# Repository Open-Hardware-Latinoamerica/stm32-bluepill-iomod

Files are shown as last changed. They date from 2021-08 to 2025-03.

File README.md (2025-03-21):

# STM32-BluePill Digital I/O Board

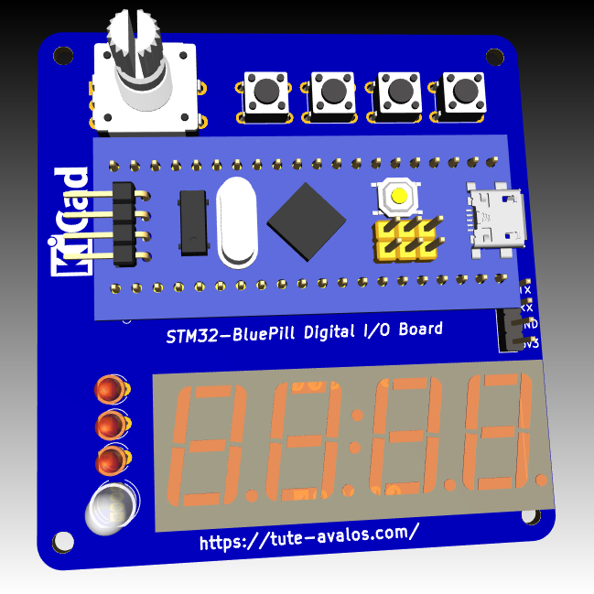
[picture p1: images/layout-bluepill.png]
STM32-BluePill Digital I/O Boadr


This Open Source Hardware PCB proyect is a tool for teach µController (microcontroller) programming. Feel free to use, modifie or improobe it in any way you want. The schematics and the layout was designed on [KiCad EDA Software](https://kicad.org/).

More information (Spanish only): [BluePill STM32 Digital I/O Board v3.0](https://blog.tute-avalos.com/2021/08/18/blue-pill-stm32-digital-i-o-board-v3-0/)

- - -

Este PCB es un poryecto de Hardware Libre y Abierto, pensado para enseñar programación de µControladores (microcontroladores). Sientase libre de usarlo, modificarlo y/o mejorarlo en cualquier sentido que desee. Los esquemáticos y el PCB fueron diseñados utilizando el software [KiCad EDA](https://kicad.org/).

- - -

# Pinout Configuration

## OUTPUTS

| PIN  | Conection | Active | | PIN  | Conection | Active |
|---|---|---|-|---|---|---|
| PB9  | LED1 - Red | LOW | | PA0  |  Seg E |  HIGH  |
| PB8  | LED1 - Green  | LOW | | PA1  |  Seg D |  HIGH  |
| PB7  | LED1 - Blue | LOW | | PA2  |  Seg P |  HIGH  | 
| PB6  | LED2 | LOW | | PA3  |  Seg C |  HIGH  |
| PB5  | LED3 | LOW | | PA4  |  Seg G |  HIGH  |
| PB4  | LED4 | LOW | | PA5  |  Seg B |  HIGH  |
| PC13 | Build-in LED  | LOW | | PA6  |  Seg F |  HIGH  |
|  - | - | - | | PA7  |  Seg A |  HIGH  |
|  - | - | - | | PB0  |  Disp 1 (MSD) |  LOW |
|  - | - | - | | PB1  |  Disp 2 |  LOW |
|  - | - | - | | PB10 |  Disp 3 |  LOW |
|  - | - | - | | PB11 |  Disp 4 (LSD) |  LOW |

## INPUTS

| PIN  | Conection | Active |
|---|---|---|
| PA15 | Rotary - A | LOW |
| PB3  | Rotary - B | LOW |
| PA8  | Rotary Switch | LOW |
| PB15 | Button 1 | LOW |
| PB14 | Button 2 | LOW |
| PB13 | Button 3 | LOW |
| PB12 | Button 4 | LOW |

## Reference

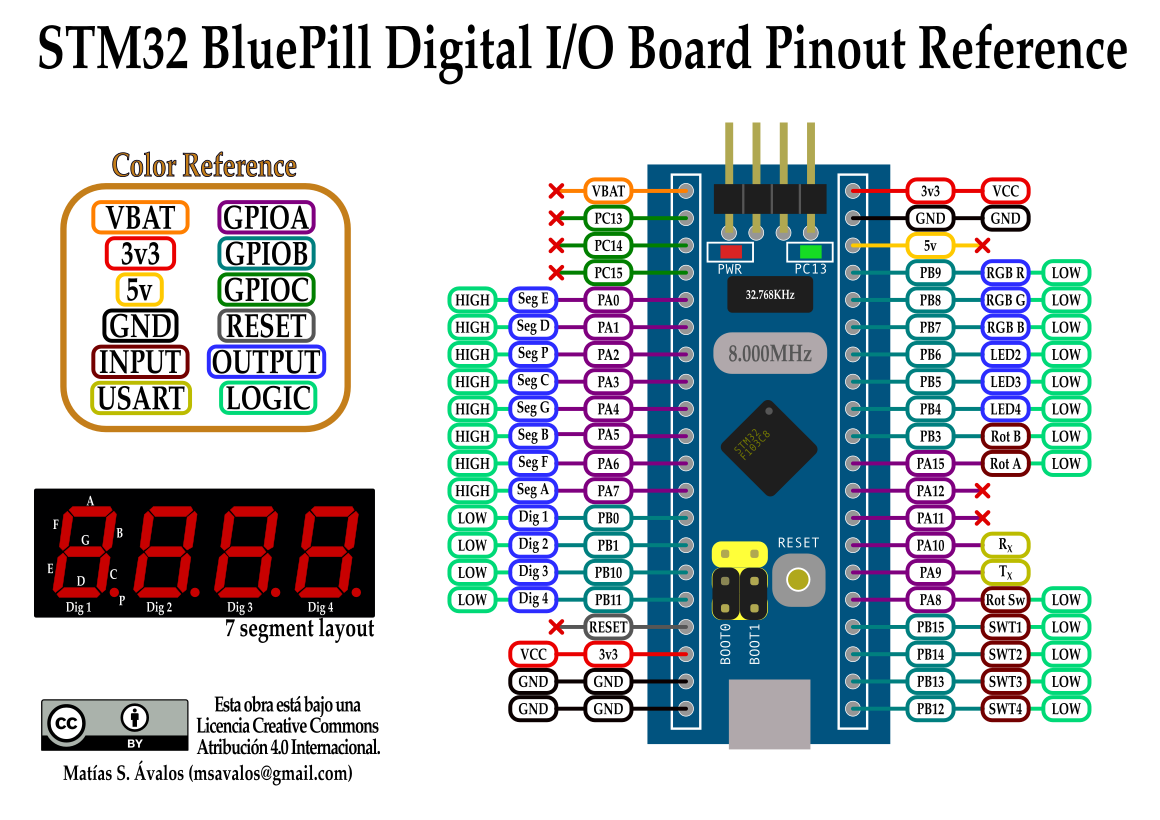
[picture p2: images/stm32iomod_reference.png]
Pinout reference


## Images

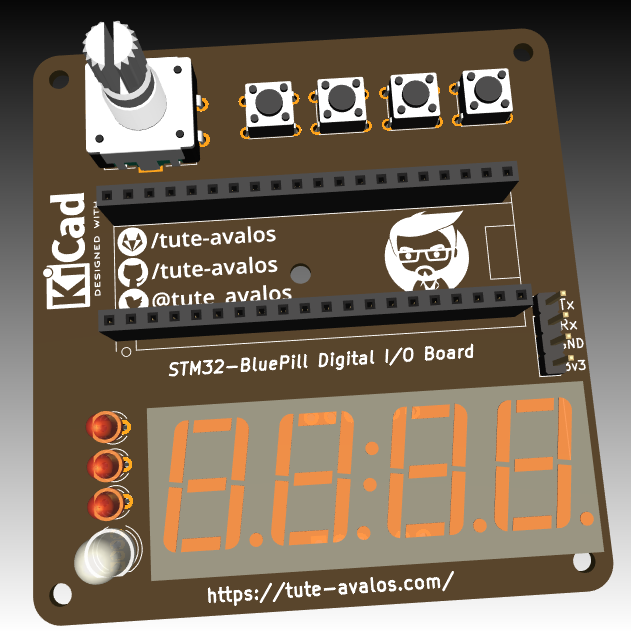
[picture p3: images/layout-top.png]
top layout
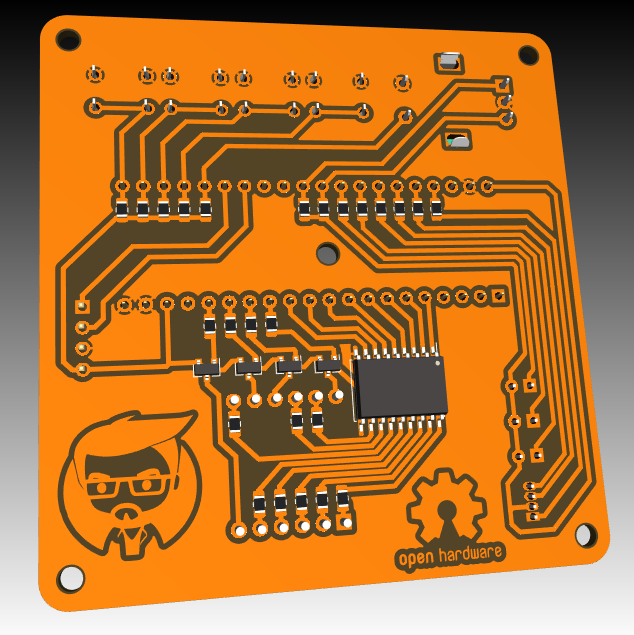
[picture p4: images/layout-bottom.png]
bottom layout
|  | |
|-|-|
|<p style="text-align:center;">top layout</p>|<p style="text-align:center;">bottom layout</p>|

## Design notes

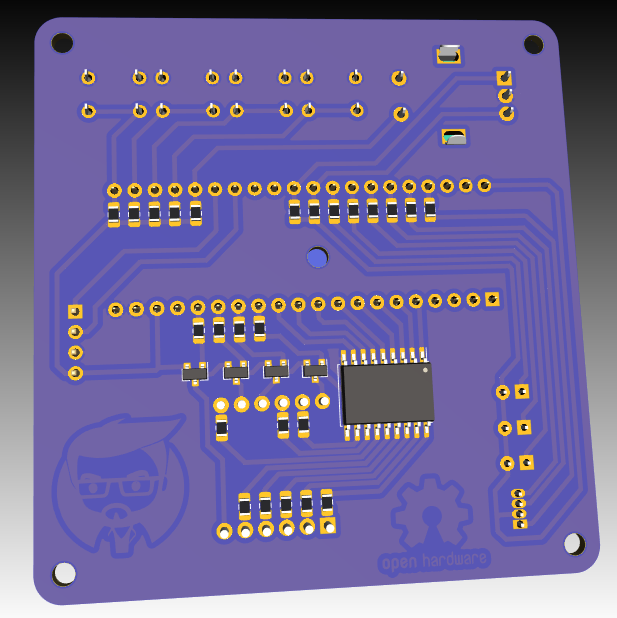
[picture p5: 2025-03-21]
images/layout-top-mask.png

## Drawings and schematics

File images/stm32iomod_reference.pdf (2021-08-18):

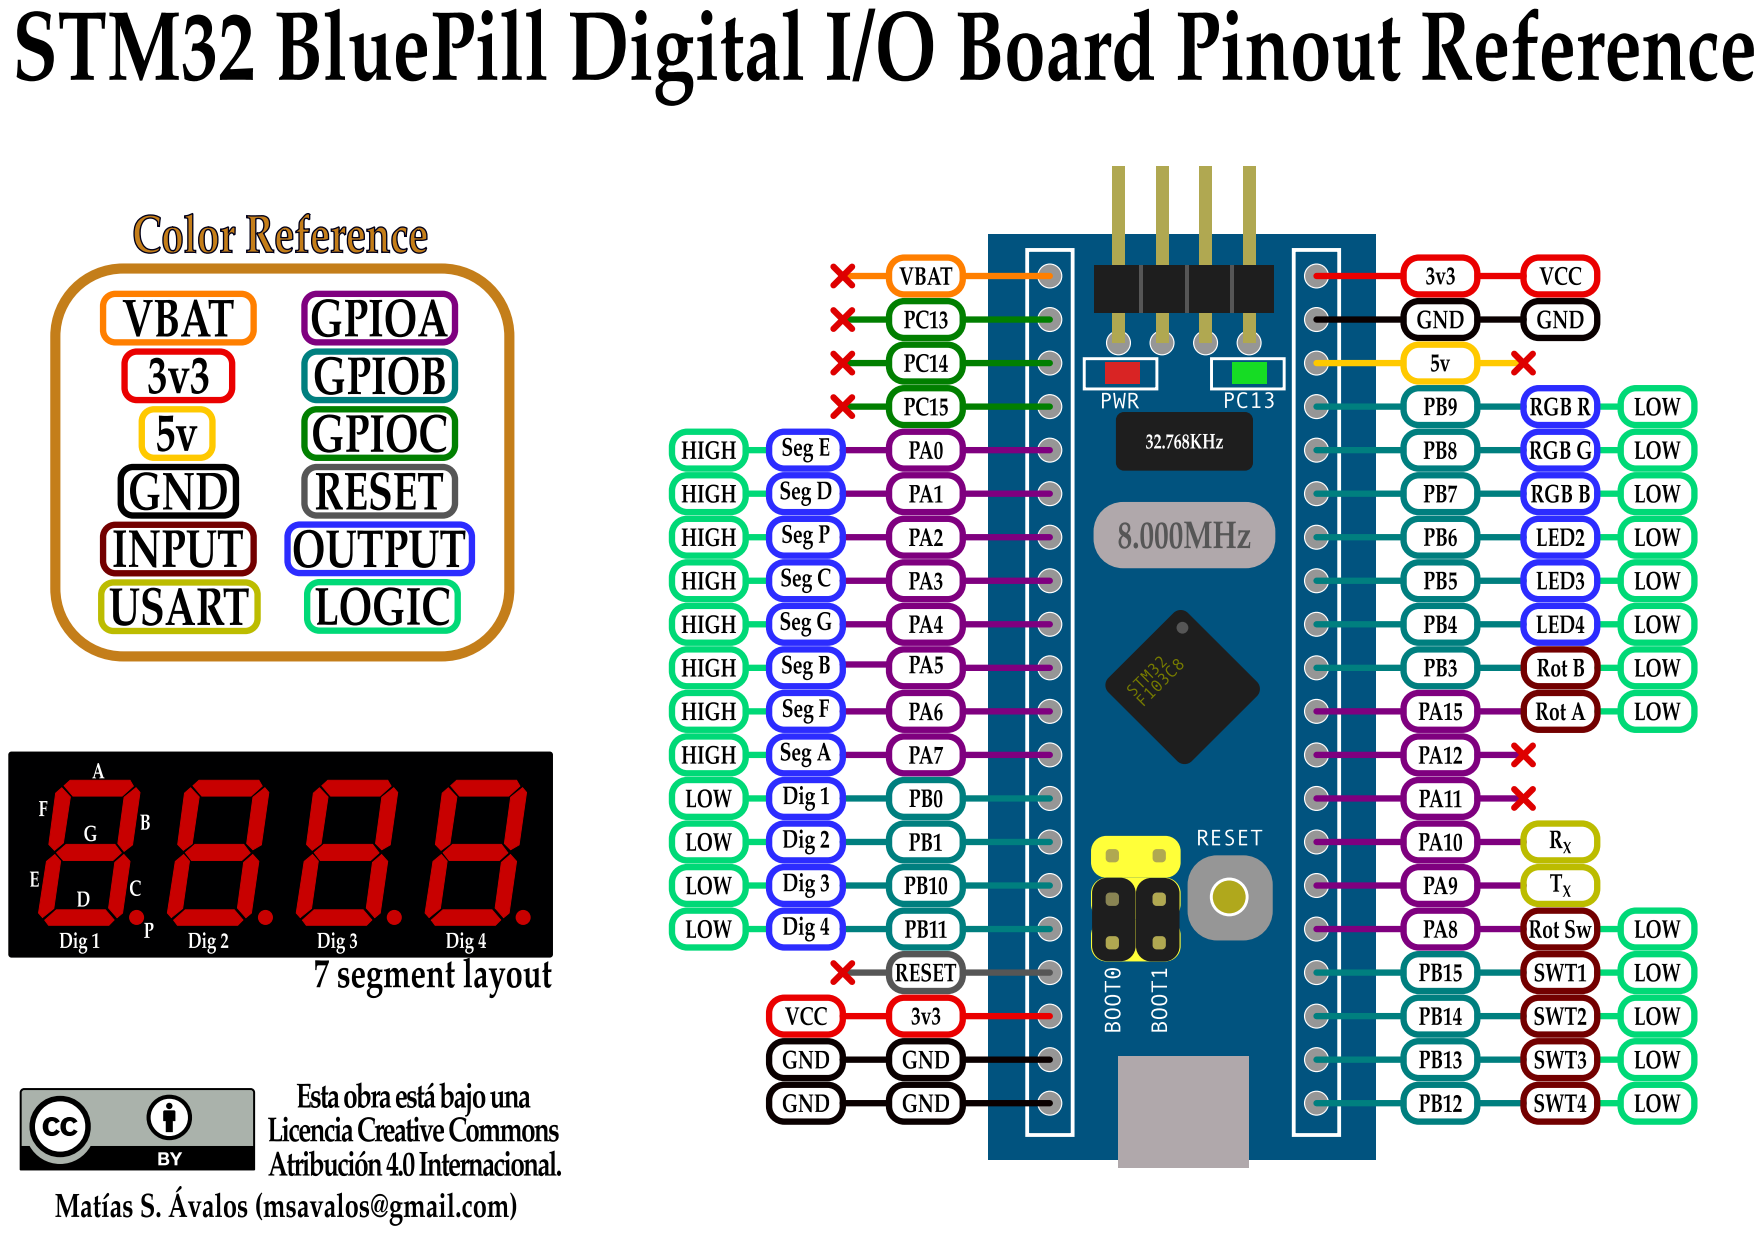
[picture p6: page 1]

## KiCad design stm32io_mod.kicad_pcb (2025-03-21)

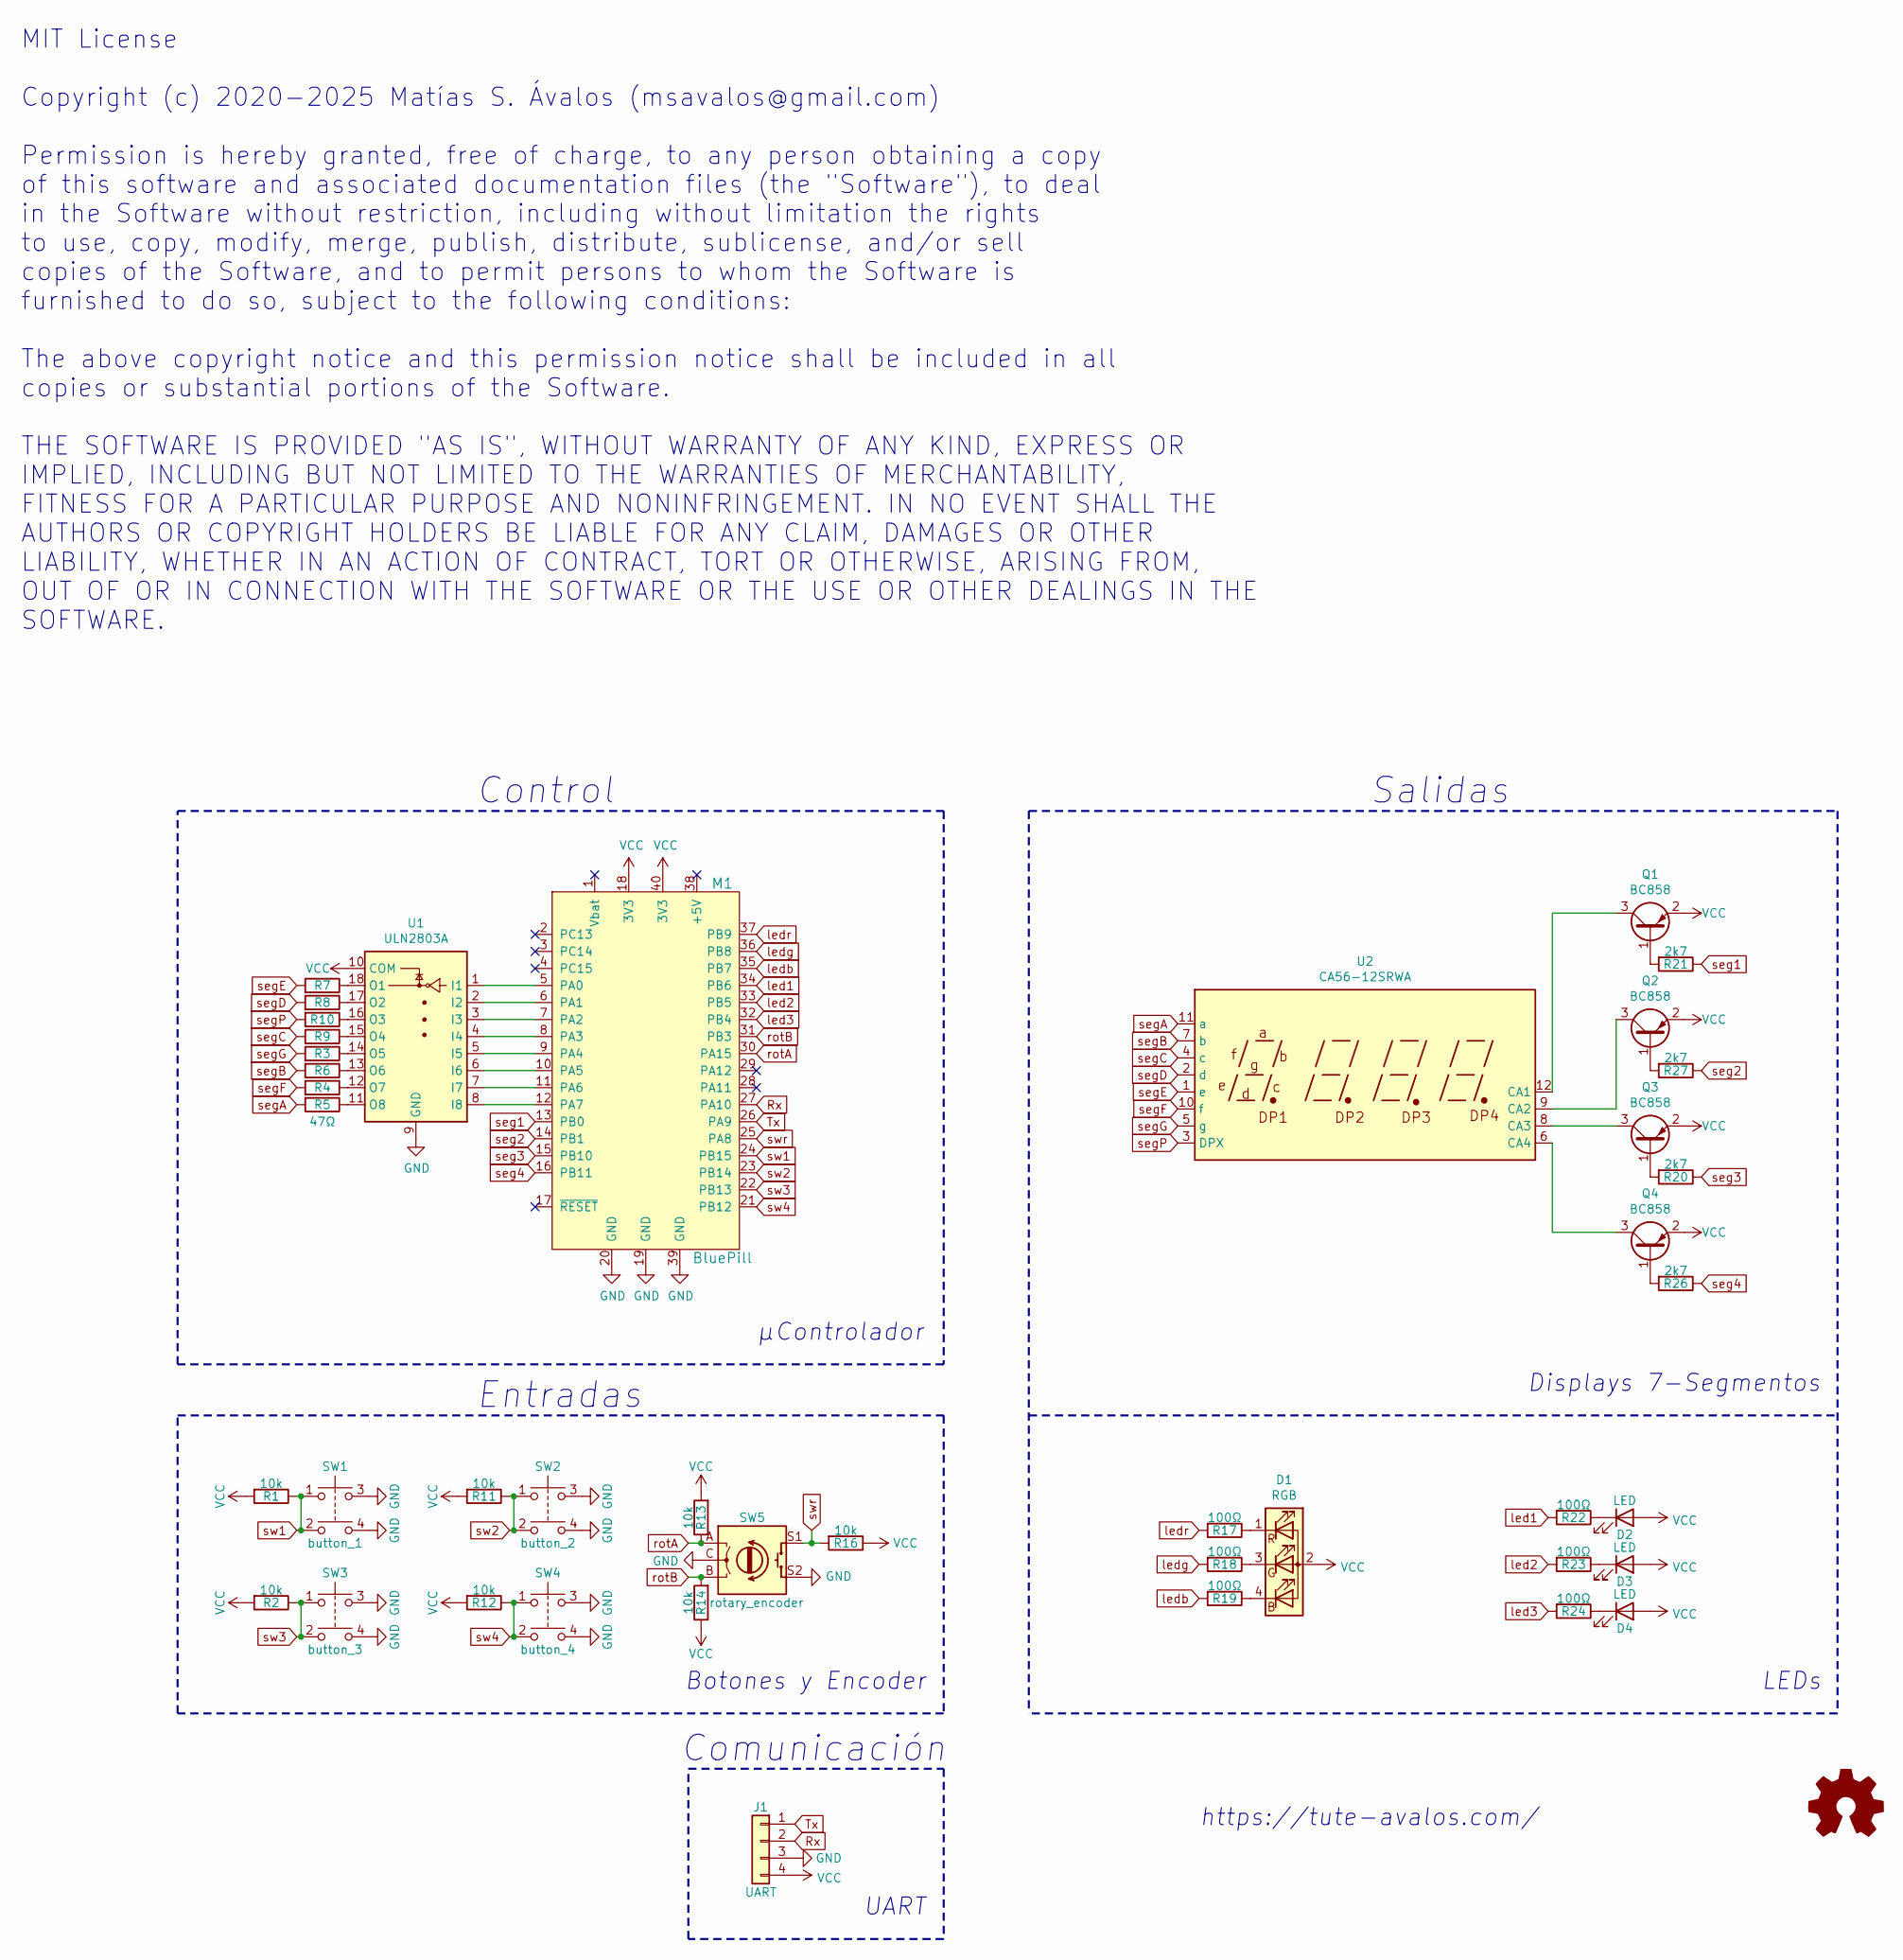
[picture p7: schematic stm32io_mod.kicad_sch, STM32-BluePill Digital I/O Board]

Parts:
D1: RGB; LED_D5.0mm-4_RGB
D2, D3, D4: LED; LED_D3.0mm_Clear
J1: UART; PinHeader_1x04_P2.54mm_Vertical
M1: BluePill
Q1, Q2, Q3, Q4: BC858; SOT-23
R1, R2, R11, R12, R13, R14, R16: 10k; R_0805_2012Metric_Pad1.15x1.40mm_HandSolder
R3, R4, R5, R6, R7, R8, R9, R10: 47Ω; R_0805_2012Metric_Pad1.15x1.40mm_HandSolder
R17, R18, R19, R22, R23, R24: 100Ω; R_0805_2012Metric_Pad1.15x1.40mm_HandSolder
R20, R21, R26, R27: 2k7; R_0805_2012Metric_Pad1.15x1.40mm_HandSolder
SW1: button_1; SW_TH_Tactile_Omron_B3F-10xx
SW2: button_2; SW_TH_Tactile_Omron_B3F-10xx
SW3: button_3; SW_TH_Tactile_Omron_B3F-10xx
SW4: button_4; SW_TH_Tactile_Omron_B3F-10xx
SW5: rotary_encoder; RotaryEncoder_Alps_EC11E-Switch_Vertical_H20mm
U1: ULN2803A; SOIC-18W_7.5x11.6mm_P1.27mm
U2: CA56-12SRWA

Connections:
GND: J1.3, M1.19 (GND), M1.20 (GND), M1.39 (GND), SW1.3, SW1.4, SW2.3, SW2.4, SW3.3, SW3.4, SW4.3, SW4.4, SW5.C, SW5.S2, U1.9 (GND)
unnamed: D1.1 (RK), R17.1
unnamed: D1.3 (GK), R18.1
unnamed: D1.4 (BK), R19.1
unnamed: D2.1 (K), R22.1
unnamed: D3.1 (K), R23.1
unnamed: D4.1 (K), R24.1
unnamed: M1.5 (PA0), U1.1 (I1)
unnamed: M1.6 (PA1), U1.2 (I2)
unnamed: M1.7 (PA2), U1.3 (I3)
unnamed: M1.8 (PA3), U1.4 (I4)
unnamed: M1.9 (PA4), U1.5 (I5)
unnamed: M1.10 (PA5), U1.6 (I6)
unnamed: M1.11 (PA6), U1.7 (I7)
unnamed: M1.12 (PA7), U1.8 (I8)
unnamed: Q1.1 (B), R21.2
unnamed: Q1.3 (C), U2.12 (CA1)
unnamed: Q2.1 (B), R27.2
unnamed: Q2.3 (C), U2.9 (CA2)
unnamed: Q3.1 (B), R20.2
unnamed: Q3.3 (C), U2.8 (CA3)
unnamed: Q4.1 (B), R26.2
unnamed: Q4.3 (C), U2.6 (CA4)
unnamed: R3.1, U1.14 (O5)
unnamed: R4.1, U1.12 (O7)
unnamed: R5.1, U1.11 (O8)
unnamed: R6.1, U1.13 (O6)
unnamed: R7.1, U1.18 (O1)
unnamed: R8.1, U1.17 (O2)
unnamed: R9.1, U1.15 (O4)
unnamed: R10.1, U1.16 (O3)
Rx: J1.2, M1.27 (PA10)
Tx: J1.1, M1.26 (PA9)
VCC: D1.2 (A), D2.2 (A), D3.2 (A), D4.2 (A), J1.4, M1.18 (3V3), M1.40 (3V3), Q1.2 (E), Q2.2 (E), Q3.2 (E), Q4.2 (E), R1.2, R2.2, R11.2, R12.2, R13.2, R14.1, R16.1, U1.10 (COM)
led1: M1.34 (PB6), R22.2
led2: M1.33 (PB5), R23.2
led3: M1.32 (PB4), R24.2
ledb: M1.35 (PB7), R19.2
ledg: M1.36 (PB8), R18.2
ledr: M1.37 (PB9), R17.2
rotA: M1.30 (PA15), R13.1, SW5.A
rotB: M1.31 (PB3), R14.2, SW5.B
seg1: M1.13 (PB0), R21.1
seg2: M1.14 (PB1), R27.1
seg3: M1.15 (PB10), R20.1
seg4: M1.16 (PB11), R26.1
segA: R5.2, U2.11 (a)
segB: R6.2, U2.7 (b)
segC: R9.2, U2.4 (c)
segD: R8.2, U2.2 (d)
segE: R7.2, U2.1 (e)
segF: R4.2, U2.10 (f)
segG: R3.2, U2.5 (g)
segP: R10.2, U2.3 (DPX)
sw1: M1.24 (PB15), R1.1, SW1.1, SW1.2
sw2: M1.23 (PB14), R11.1, SW2.1, SW2.2
sw3: M1.22 (PB13), R2.1, SW3.1, SW3.2
sw4: M1.21 (PB12), R12.1, SW4.1, SW4.2
swr: M1.25 (PA8), R16.2, SW5.S1

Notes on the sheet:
Displays 7-Segmentos
Salidas
Entradas
Comunicación
Botones y Encoder
LEDs
Control
UART
µControlador
MIT License Copyright (c) 2020-2025 Matías S. Ávalos (msavalos@gmail.com) Permission is hereby granted, free of charge, to any person obtaining a copy of this software and associated documentation files (the "Software"), to deal in the Software without restriction, including without limitation the 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
https://tute-avalos.com/

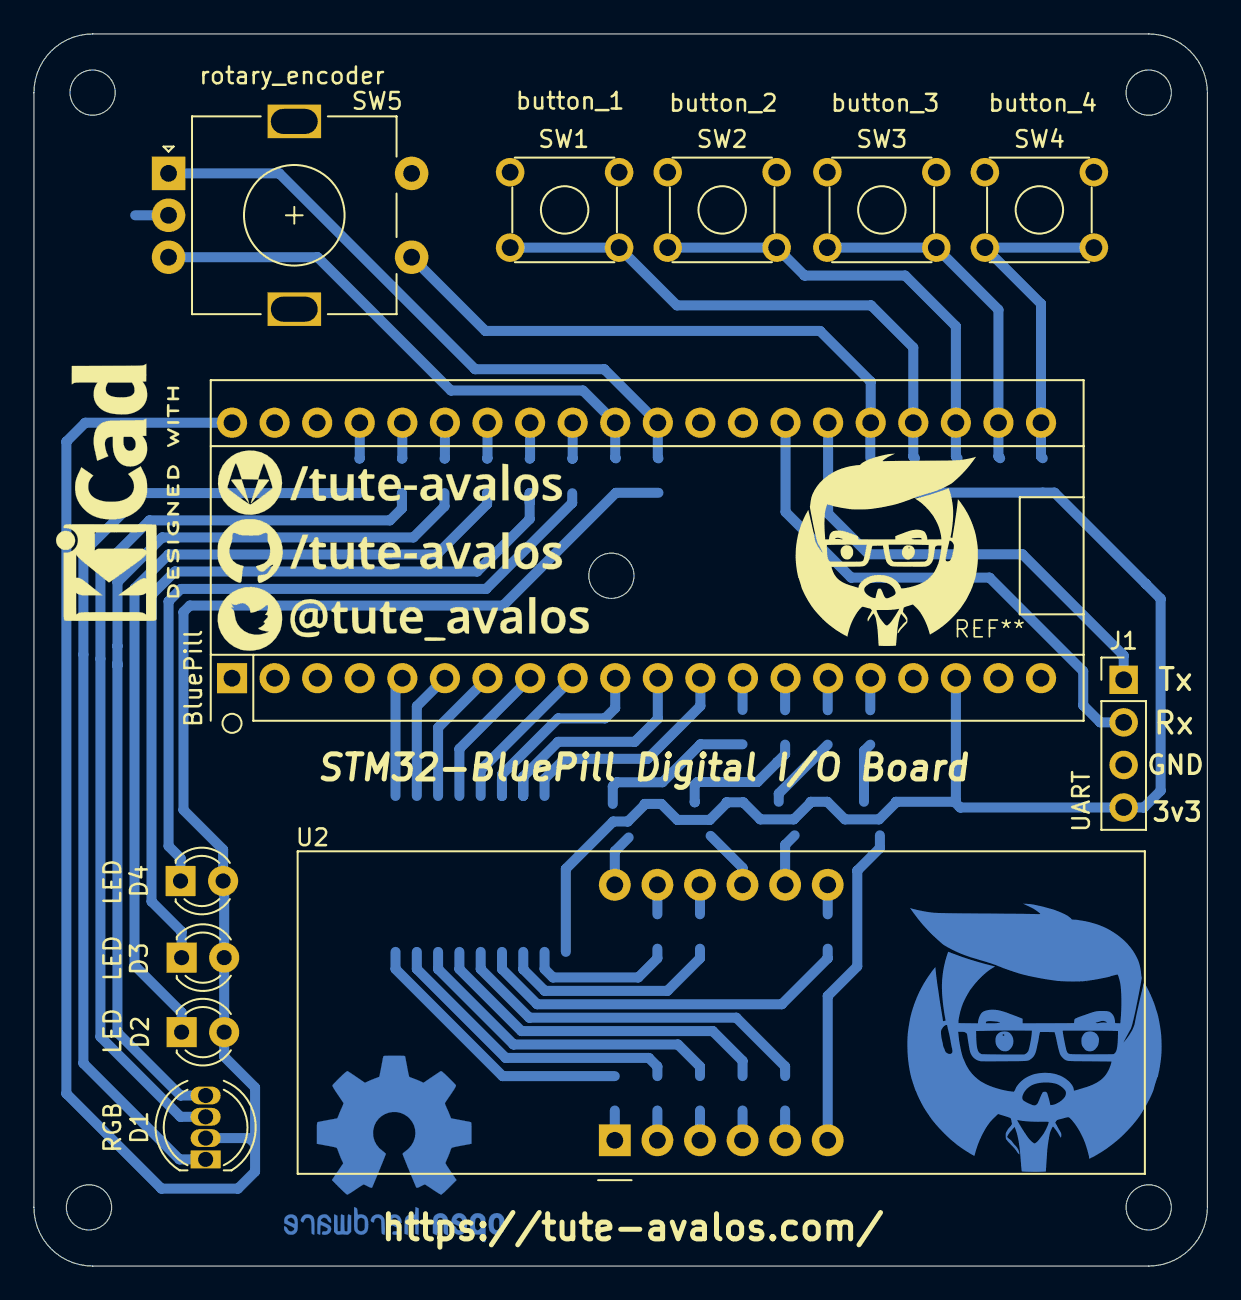
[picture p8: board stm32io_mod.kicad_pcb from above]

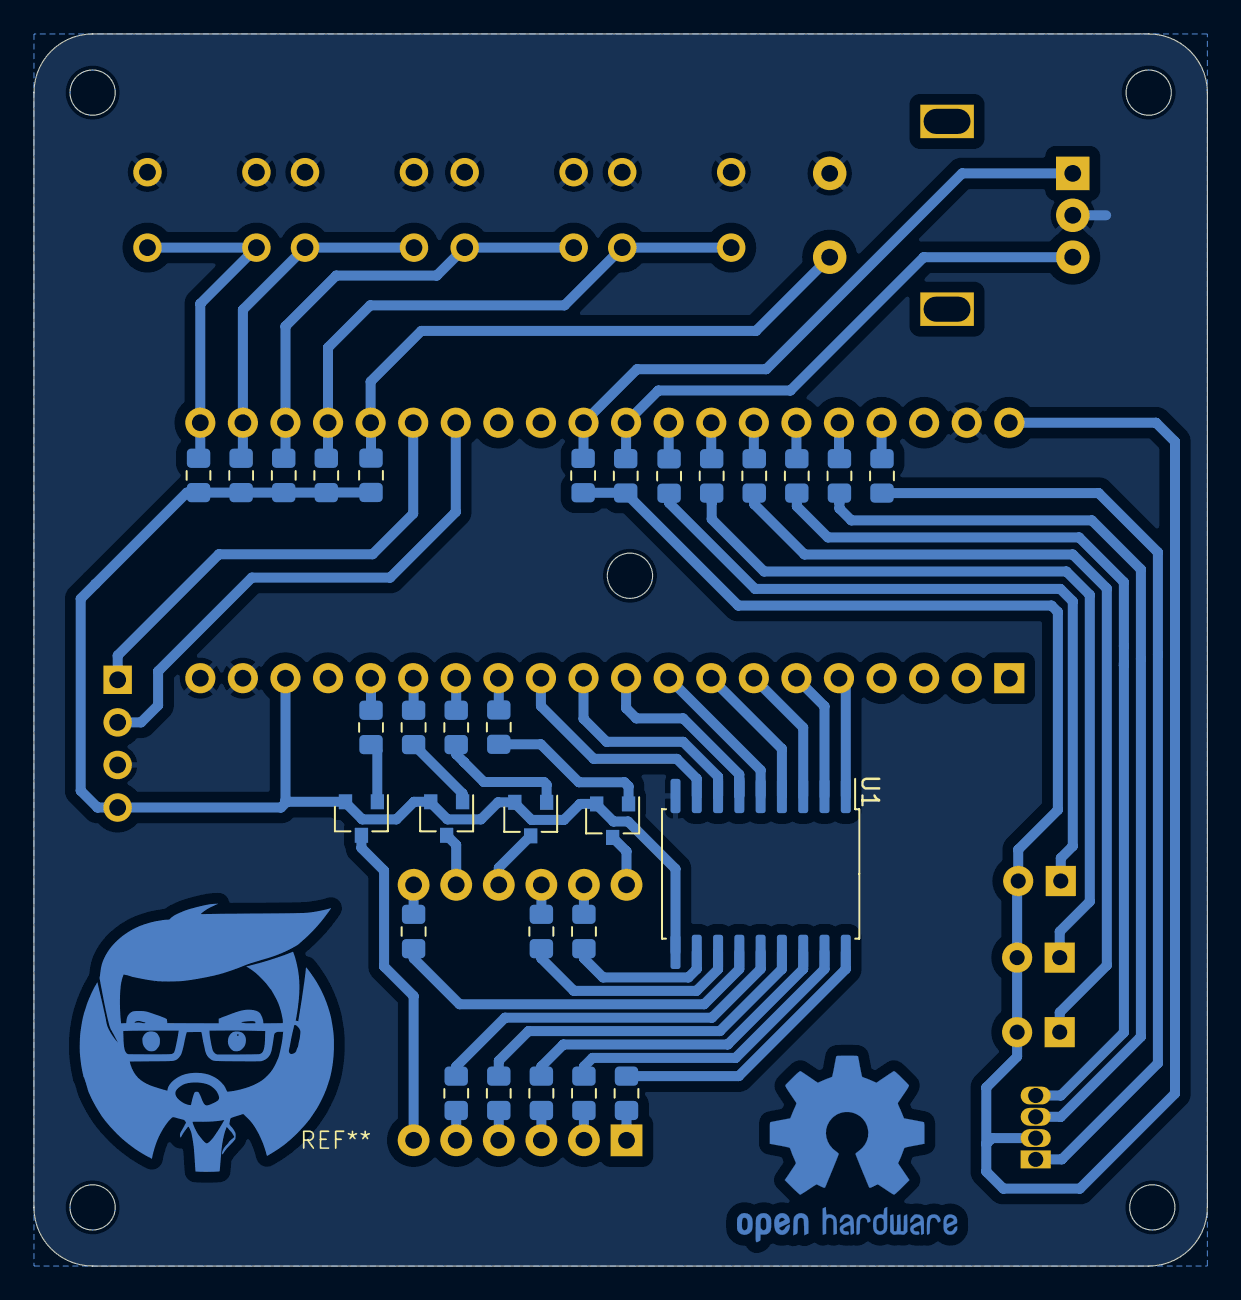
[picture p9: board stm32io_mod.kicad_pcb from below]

Board: 2 copper layers, 70.0 x 73.5 mm, 43 parts (30 on the bottom side), 59 nets.

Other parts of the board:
Social: Links; electronlinux-social-22x12

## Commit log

2020-02-27 Primer commit
    [stm32io_mod.kicad_pcb, stm32io_mod.sch]
2020-02-28 Se añade licencia
    [stm32io_mod.kicad_pcb, stm32io_mod.sch]
2020-02-29 Cambio de README a README.md
2020-02-29 Descripción de pines en el README
2020-03-02 cambio de resistencias a smd
    [stm32io_mod.kicad_pcb, stm32io_mod.sch]
2020-03-03 Pequeños arreglos en el PCB
    [stm32io_mod.kicad_pcb, stm32io_mod.sch]
2020-03-10 Agregado VCC al pinhead de la UART
    [stm32io_mod.kicad_pcb, stm32io_mod.sch]
2020-03-11 Se agregó una linea de gnd entre el rotary
    [stm32io_mod.kicad_pcb]
2020-05-21 Cambio de polaridad de los LEDs 2-5
    [stm32io_mod.kicad_pcb, stm32io_mod.sch]
2020-06-12 Se corrigió la polaridad de los leds y el README
2020-06-23 Corrección en la serigrafía de la bluepill y UART
    [stm32io_mod.kicad_pcb, stm32io_mod.sch]
2020-09-03 Cambio de lugar del rotary
    [stm32io_mod.sch]
2020-09-06 retoques finales
    [stm32io_mod.kicad_pcb]
2021-01-03 Se modificaron las imágenes de referencias y tablas
2021-01-11 Agregadas imagenes en el README
2021-08-18 Se mejoró el plano de masa
    [stm32io_mod.kicad_pcb, stm32io_mod.sch]
2021-08-18 Corrección en el README.md
2021-11-08 Update README.md
    https://forum.kicad.info/t/warning-avoid-all-links-to-kicad-pcb-org-use-kicad-org/31521
2025-02-27 se actualizan las serigrafías a nuevos logos y nueva url
    [stm32io_mod.kicad_pcb, stm32io_mod.kicad_sch]
2025-02-27 Se modifica el readme
2025-03-21 Se ajustaron los screenshots
    [stm32io_mod.kicad_pcb, stm32io_mod.kicad_sch]
2025-03-21 ajuste menor en el README

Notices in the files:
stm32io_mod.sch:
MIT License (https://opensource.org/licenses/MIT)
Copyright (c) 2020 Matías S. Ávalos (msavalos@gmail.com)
